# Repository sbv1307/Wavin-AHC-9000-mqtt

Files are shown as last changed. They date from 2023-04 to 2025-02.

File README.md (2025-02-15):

# **Wavin-AHC-9000-mqtt**

A Esp8266 mqtt interface for more Wavin AHC-9000 controllers connected together, configured and controlled by one Wavin display.

The goal is to be able to control the Wavin AHC 9000 heating controllers from [Home Assistant](https://www.home-assistant.io/) (HA), and still be able to use the Wavin display as well. However MODBUS specifications does not allow more than one master. The Wavin display will not be working together with the Esp8266 mqtt interface, at the same tine, in the current version. The current solution is to use a 4 poles toggle switch, to manually switch between the Esp8266 mqtt interface and the Wavin display.

The original goal of being able to control the Wavin AHC 9000 heating controllers from [OpenHAP](https://www.openhab.org/), has been abandoned because I gave up finding a discovery function for MQTT integrations, like the one in HA.

### **Operation**

The Esp8266 mqtt interface is generally operated from [HA](https://www.home-assistant.io/). When started, it will publish a configuration for each thermostat connected to a MQTT Broker, from where HA will pickup the configurations.

Besides controlling the single thermostat from HA, the Esp8266 mqtt interface provide a MQTT switch for HA named "Wavin interface operation mode", which provide an easy way to change the setpoints for all thermostats connected. Currently four operations modes are configured in the PrivateConfig.h file:
  
0. Normal operation
1. Holiday operation
2. Surplus heat operation
3. Maintenance operation**

These operations modes can also be selected by publishing a [JSON](https://en.wikipedia.org/wiki/JSON) to:
````bash
heat/floorE8DB84E05CC8/config

````
Publish the following JSON will set the operation mode to **Holiday operation**
````bash
{
  "opmode": "1"
}
````

**Maintenance operation:** This operation mode will set the setpoint temperature for all thermostats to maximum temperature (MAX_TEMP) and run in this mode for a period of time, and then return to previous operation mode. All parameters are defined in PrivateConfig.h

### **Current project status**

The Wavin AHC-9000 controllers are initial installed and configured using the Wavin display, which configures each controller's MOC-BUS device number.

Future solution might be to use a 2 Circuit IC Switch [CD4052B](https://www.ti.com/product/CD4052B-MIL#tech-docs), managed by the Esp8266 mqtt interface, to control which controller (Wavin display or Esp8266) will be in action.

### **History**

This project has started as a git clone of [dkjonas/Wavin-AHC-9000-mqtt](https://github.com/dkjonas/Wavin-AHC-9000-mqtt.git) but restructured for Firmware (FW), Software (SW) and Hardware (HW).

This project takes on the challenge mentioned in [Issue #3](https://github.com/dkjonas/Wavin-AHC-9000-mqtt/issues/3#issuecomment-435690672)

##### "connect two AHC's together and control them by one display. I think this is rather unusual setup, so my code doesn't handle this case; It can only control one AHC."

Another interesting project: [nic6911/Wavin-AHC-9000-mqtt](https://github.com/nic6911/Wavin-AHC-9000-mqtt)

## **Esp8266 mqtt interface**

See the cloned Firmware markdown [here](Firmware/README.md).

## **SOFTWARE**

### Configuration

src/PrivateConfig.h contains constants, that should be changed to fit your own setup.

#### Notes for some of the constants:
MODBUS_DEVICES[] 
>This array defines the Modbus device id, for the AHC9000 Control Units, connected.<br> 
When AHC9000 Control Units are connected together with the AHC9000 Touch Screen Display (Display), 
then Modbus ID's are configured by the Display.<br>
The ID's are in binary representation starting with 0x02<br>
Having two AHC9000 Control Units connected, the definition will be:
````bash
MODBUS_DEVICES[] = {0x02, 0x03};
````

NUMBER_OF_CHANNELS_MONITORED_PER_DEVICE[]
>This is an array, defines how many AHC9000 Thermostats are connected to / monitored by each AHC9000 Control Units.<br>
When 11 Thermostats are connected to AHC9000 Control Unit 0x02 and 4 Thermostats are connected to AHC9000 Control Unit 0x03, the definition vill be:
````bash
NUMBER_OF_CHANNELS_MONITORED_PER_DEVICE[] = {11, 4}
````

ELEMENT_OFFSET_ON_ROOMS_FOR_DEVICE[]
>This array is used to define number of elements in other arrays and to find specific element in in these other arrays.<br>
Elements in other arrays represents Thermostats connected.<br>
The first element in this array is always zero. <br>
The next element (the second element) is the number of Thermostats connected to the first AHC Controller. <br>
The third element is the number of Thermostats connected to the first AHC Controller plus the number of Thermostats connected to the second AHC Controller.
The foruth element is the number of Thermostats connected to the first AHC Controller plus the number of Thermostats connected to the second AHC Controller plus the number of Thermostats connected to the third AHC Controller.<br>
And so on...
The last element in this array will represent the total number of Thermostats conencted / monitored.<br>
This way number of elements in other arrays can be defined as:<br>
bool configurationPublished[PrivateConfig::ELEMENT_OFFSET_ON_ROOMS_FOR_DEVICE[PrivateConfig::NUMBER_OF_DEVICES]];
Elements in an array can be found by:<br>
configurationPublished[ (PrivateConfig::ELEMENT_OFFSET_ON_ROOMS_FOR_DEVICE[device]) + channel]<br>
Where "channel" represent the Thermostat for the "device" in question.
When 11 Thermostats are connected to AHC9000 Control Unit 0x02 and 4 Thermostats are connected to AHC9000 Control Unit 0x03, the definition vill be:
````bash
ELEMENT_OFFSET_ON_ROOMS_FOR_DEVICE[] = {0,11,15}
````

### Compiling

The sketch use [PubSubClient](https://docs.arduino.cc/libraries/pubsubclient/)2.6 and [ArduinoJson](https://github.com/bblanchon/ArduinoJson/releases)7.0.1. Add the following to the plarform.ini file.
````bash
lib_deps =
  PubSubClient@2.6
  bblanchon/ArduinoJson@7.0.1
````

Larger buffer is needed for HomeAssistant discovery messages, which are quite large.

Add the following to the plarform.ini file.
````bash
build_flags = -D MQTT_MAX_PACKET_SIZE=1024
````
Over The Air update (OTA) is implemented in main.cpp. 

Compiled with [PlatformIO](https://platformio.org/) installed in VS Code and adding the follow to platformio.ini the code will provide the possability of setting PlatformIO Project Environment to   `env:nodemcu_ota` and upload will happen OTA.

````bash
[env:nodemcu_ota]
extends = env:nodemcu
upload_protocol = espota
upload_port = <IP Address of NodeMCU>
````

## **Mosquitto broker**

### **Requirements**

- Raspberry Pi model B v1.2. Installed with Raspberry Pi OS Lite (32-bit) <span id="a1">[[1]](#f1)</span>.
- Internet access.
- Docker Engin and Docker Compose installed <span id="a2">[[2]](#f2)</span>.

### **Create docker-compose file**

In folder `Wavin-AHC-9000-mqtt` create file `docker-compose.yaml`

```bash
vi docker-compose.yaml
```

Add the following contend:

```bash
# Docker-compose file for building Wavin-AHC-9000-mqtt program stack.

# Generel note about environment settings - see README.md file about .env file

version: '3.8'

services:
  mosquitto-mqtt:
  container_name: mosquitto-mqtt
  image: eclipse-mosquitto:2
  restart: always
  command: mosquitto -c /mosquitto-no-auth.conf
  ports:
    - 1883:1883
  volumes:
    - mosquitto-conf:/mosquitto/config
    - mosquitto-data:/mosquitto/data
    - mosquitto-log:/mosquitto/log

volumes:
  mosquitto-conf:
    name: mosquitto-conf
  mosquitto-data:
    name: mosquitto-data
  mosquitto-log:
    name: mosquitto-log

````

 Start the docker container with `docker-compose up -d`.

```bash
docker-compose up -d
```

## Change LOG

| | Module | Version | Change
|--- |--- | ---- |----
| | | 0.0.1 | Initial commit. On-board LED at PIN 16 added to indicate active boot up. It turns off at successful connect to Wireless Lan. 
| FW | WavinController.h | 0.0.2 | MODBUS_DEVICE changed from = 0x01 to 0x02
| FW | WavinController.h | 0.0.3 | MODBUS_DEVICE changed from = 0x02 to 0x03
| FW | WavinController.h | 0.0.4 | Added MODBUS_DEVICES and NUMBER_OF_DEVIDES
| FW | WavinController.cpp | 0.0.4 | Objects modified to handle MODBUS_DEVICE as an argument instad of fixed value.
| FW | All modules | 0.0.4 | Calls to objects, which has changed because of the objects being modified for handle MODBUS_DEVICE as an argument. MQTT Publish functions has been added Modbus Device.
| FW | main.cpp | 0.0.5 | publishConfiguration() changed to comply with homeassistant topic.
| FW | main.cpp | 0.0.6 | Implementing OTA update.
| FW | main.cpp | 0.0.7 | OTA and temerature setting issues.
| FW | main.cpp & PrivateConfig.h | 0.0.8 | Configurable names for chanels added to PrivateConfig.h and implemented in mail.cpp
| FW | main.cpp | 0.0.9 | Re-arrange code structure. Insert function definitions, startup() and loot() in beginning.
| FW | main.cpp | 0.0.10 | #4: Insert WiFi reconnect postpone time <br>#5: call WiFi.disconnect() before "reconnect" (WiFi.mode(WIFI_STA) og WiFi.begin() <br>#2: Publish device info to MQTT broker
| FW | main.cpp | 0.0.11 | #3: implement Arduino JSON
| FW | main.cpp | 0.1.0  | #11: millis() overrun: Implementing sec() and change code from using milli seconds, to use secunds for timestamps
| FW | main.cpp | 0.1.1  | #10: Scan only installed sensors<br>PrivateConfig.h streamlined with WavinController.h. Global constants moved into class PrivateConfig as static ...
| FW | main.cpp | 0.1.2  | Tracking wavinController.readRegisters. This version publishes failed calls to readRegisters in order og verify how long it stakes before alle Thermostats are read.
| FW | main.cpp | 0.1.3  | #8: Implement reading of floor temperature
| FW | main.cpp | 0.1.4  | Track unsuccessful for calls to wavinController.readRegisters
| FW | main.cpp | 1.0.0  | #6: Preset functionality (Holiday function, Removal of surplus heat)
| FW | main.cpp | 1.1.0  | #9 Implement Maintenance fuktionality 
| FW | main.cpp | 1.2.0  | Setpoints 
| FW | main.cpp | 1.2.1  | Setpoints bugfixes.
| FW | main.cpp | 1.2.3  | #12 Set temperature not change, when changing operation mode 

###### "#n" Refers to github issue number

## Credits
- dkjonas/Wavin-AHC-9000-mqtt

#### **Footnotes**
=======
###### 1. <span id="f1"></span> See document: [Setting up and configure Raspberry Pi 3 MODEL B+ for the Docker Traefik router project](./docs/SettingUpRaspberryPi.md). [$\hookleftarrow$](#a1)

###### 2. <span id="f2"></span> See document [Install Docker Engin and Docker Compose](./docs/InstallDockerEnginAndCompose.md)[$\hookleftarrow$](#a3)

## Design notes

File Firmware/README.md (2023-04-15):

# Wavin-AHC-9000-mqtt
This is a simple Esp8266 mqtt interface for Wavin AHC-9000/Jablotron AC-116, with the goal of being able to control this heating controller from a home automation system.

## Hardware
The AHC-9000 uses modbus to communicate over a half duplex RS422 connection. It has two RJ45 connectors for this purpose, which can both be used. 
The following schematic shows how to connect an Esp8266 to the AHC-9000:
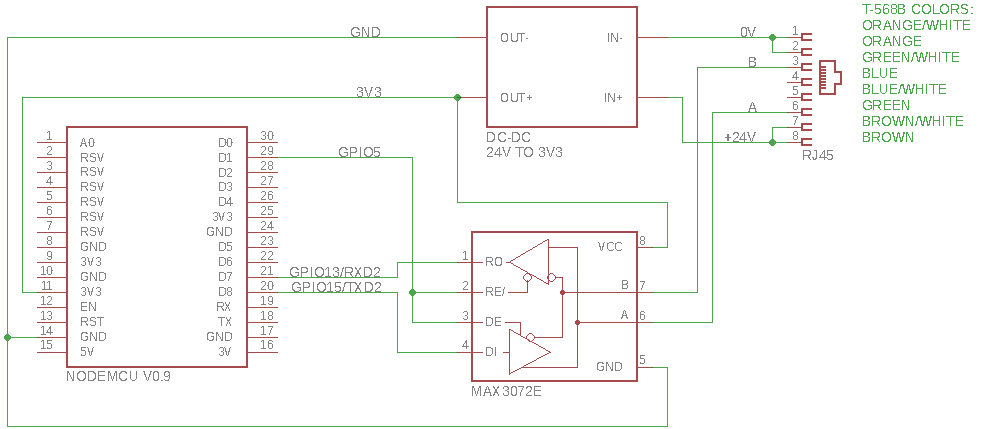
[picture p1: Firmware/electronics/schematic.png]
Schematic


Components with links to devices on eBay
* Esp8266. I use a [NodeMcu 0.9](https://www.ebay.com/itm/NEW-Version-NodeMcu-Lua-ESP8266-CH340-WIFI-Internet-Development-Board-Module/311413475392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), mostly because it is very convenient to have the onboard USB interface for programming. Almost anything with an Esp8266 on it will work.
* [24V to 3v3 switchmode converter](https://www.ebay.com/itm/DC-Buck-24V-12V-9V-to-3-3V-3A-Step-Down-Converter-Voltage-Regulator-Power-Module/173494900654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). This is only needed if you want to power the Esp8266 from the AHC-9000. A 24V to 5V converter can also be used, if it is connected to the +5V input of the NodeMcu. Please note that not all 3V3 step down converters on eBay supports 24V input
* [MAX3072E](https://www.maximintegrated.com/en/products/interface/transceivers/MAX3072E.html) for converting the 3V3 serial output from the Esp8266 to RS422. There are many similar IC's from other suppliers, which can also be used. Speed is limited, and cables can be kept short, so this is rather uncritical. Note though, that it should be a 3V3 version. [MAX3485](https://www.ebay.com/itm/5pcs-MAX3485CPA-DIP-DIP-8-MAX3485-3-3V-Powered-Transceiver-new/400985402735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) should be compatible, and can be found on eBay.
* RJ45 connector. This can be omitted by soldering a patch cable directly to the circuit.

Depending on the used Esp8266 board and/or the switchmode converter used, it may be benificial to add a larger capacitor in the range of 100uF between 3V3 and gnd.  This will most likely help if you experience WiFi connection/stability issues.

## Software

### Configuration
src/PrivateConfig.h contains 5 constants, that should be changed to fit your own setup.

`WIFI_SSID`, `WIFI_PASS`, `MQTT_SERVER`, `MQTT_USER`, and `MQTT_PASS`.

### Compiling
I use [PlatformIO](https://platformio.org/) for compiling, uploading, and and maintaining dependencies for my code. If you install PlatformIO in a supported editor, building this project is quite simple. Just open the directory containing `platformio.ini` from this project, and click build/upload. If you use a different board than nodemcu, remember to change the `board` variable in `platformio.ini`.
You may be able to use the Arduino tools with the esp8266 additions for compiling, but a few changes may be needed, including downloading dependencies manually.

### Testing
Assuming you have a working mqtt server setup, you should now be able to control your AHC-9000 using mqtt. If you have the [Mosquitto](https://mosquitto.org/) mqtt tools installed on your mqtt server, you can execude:
```
mosquitto_sub -u username -P password -t heat/# -v
```
to see all live updated parameters from the controller.

To change the target temperature for a output, use:
```
mosquitto_pub -u username -P password -t heat/floorXXXXXXXXXXXX/1/target_set -m 20.5
```
where the number 1 in the above command is the output you want to control and 20.5 is the target temperature in degree celcius. XXXXXXXXXXXX is the MAC address of the Esp8266, so it will be unique for your setup.

### Integration with HomeAssistant
If you have a working mqtt setup in [HomeAssistant](https://home-assistant.io/), all you need to do in order to control your heating from HomeAssistant is to enable auto discovery for mqtt in your `configuration.yaml`.
```
mqtt:
  discovery: true
  discovery_prefix: homeassistant
```
You will then get a climate and a battery sensor device for each configured output on the controller.

If you don't like auto discovery, you can add the entries manually. Create an entry for each output you want to control. Replace the number 0 in the topics with the id of the output and XXXXXXXXXXXX with the MAC of the Esp8266 (can be determined with the mosquitto_sub command shown above)
```
climate wavinAhc9000:
  - platform: mqtt
    name: floor_kitchen
    current_temperature_topic: "heat/floorXXXXXXXXXXXX/0/current"
    temperature_command_topic: "heat/floorXXXXXXXXXXXX/0/target_set"
    temperature_state_topic: "heat/floorXXXXXXXXXXXX/0/target"
    mode_command_topic: "heat/floorXXXXXXXXXXXX/0/mode_set"
    mode_state_topic: "heat/floorXXXXXXXXXXXX/0/mode"
    modes:
      - "heat"
      - "off"
    availability_topic: "heat/floorXXXXXXXXXXXX/online"
    payload_available: "True"
    payload_not_available: "False"
    qos: 0

sensor wavinBattery:
  - platform: mqtt
    state_topic: "heat/floorXXXXXXXXXXXX/0/battery"
    availability_topic: "heat/floorXXXXXXXXXXXX/online"
    payload_available: "True"
    payload_not_available: "False"
    name: floor_kitchen_battery
    unit_of_measurement: "%"
    device_class: battery
    qos: 0
```

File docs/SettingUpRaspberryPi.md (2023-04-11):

# Setting up and configure Raspberry Pi 3 MODEL B+ for the Docker projects

## Pre-requisuits:
    • USB Keyboard
    • Terminal kabel (HDMI → VGA)
    • LAN kabel (Internet access)
    • Raspberry Pi
    • FAST SC kort

## Setting up SD card:
Using Raspberry Pi Imanager to create SD Card installed with Raspberry Pi OS Lite (32-bit).

See: [Setting up your Raspberry Pi](https://projects.raspberrypi.org/en/projects/raspberry-pi-setting-up/2) for detailed instructions.

## Configure Raspberry Pi 3 MODEL B+ for the Docker projects

    • Connet: 
      - LAN kabel (Internet access), 
      - local keyboard and
      - terminal.
    • Take a note about LAN address at boot up.
    • Boot up and log in as:
      - User: pi
      - Passwd: raspberry

## Run Raspberry Pi configuration by executing

````bash
sudo raspi-config
````

### Update this tool to lates version - Main menu item 8

    • Select item: 8 Update this tool to latest version.

### System options - Main menu item 1:

##### As the pi will be running in a demilitarized zone, wireless network will not be configured.

    • Submenu S4 Hostname = pi-mqtt
    • Submenu S6 Network at Boot = Yes

### Interface Options - Main menu item 3:
    • Submenu P2 SSH = remote command line access using SSH = Enable.

### Perfoamance Options - Main menu item 4:
    • P4 Fan: GPIO 18 → Temp: 80.

### Localisation Options - Main menu item 5:
    • L1 Locale →  add:  da_DK-UTF-8 UTF-8
    • L2 TimeZone → Europe → Copenhagen.
    • L3 Keyboard → Generid 105-key PC (intl) → Danish (With Win keys) → default → No comppose key.

### Advanced Options - Main menu item 6:
    • A1 Expand Filesystem.

## **Exit raspi-config and reboot** -> Login and verify IP addresses

<br>

# From here on - Connect via SSH with PUTTY
## Update OS: 
```bash
 sudo apt-get update
 sudo apt-get -y upgrade –fix-missing
 sudo reboot now

```

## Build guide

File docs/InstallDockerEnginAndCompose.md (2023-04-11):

# Install Docker Engin and Docker Compose

## **Log in as mqttmgr and run the commands below:**

## remove any previously docker installation.
```bash
sudo apt-get remove docker docker-engine docker.io containerd runc
````

Expected output:

````bash
Reading package lists... Done
Building dependency tree... Done
Reading state information... Done
E: Unable to locate package docker-engine
````

## Get docker engine and run install schript
```bash
curl -sSL https://get.docker.com | sh
```

## Enable user ”mqttmgr” to run docker withour using sudo
```bash
sudo usermod -aG docker mqttmgr
```

## **Log out and log in again to run docker commands withour sudo**
```bash
exit
```

## Test docker installation
```bash
docker run hello-world
```
If the installation of docker is successful, then message **Hello from Docker!** will show up.

## Clean up docker to verify docker-compose
```bash
docker rm -f  $(docker ps -aq)
```
```bash
docker rmi $(docker images -aq)
```

## Install dependincies for installing docker compose
```bash
sudo apt-get install -y libffi-dev libssl-dev
```
```bash
sudo apt-get install -y python3 python3-pip
```
```bash
sudo apt-get remove python-configparser

```

## Install docker compose
```bash
sudo pip3 -v install docker-compose
```

## Test docker-compose:
On Linux host create file **docker-compose.yml** and adde the following lines:
```bash
version: '3.4'
services:
  hello-world:
    image: hello-world
```
PS: If using **vi**, the folowing commands are usefull:
```bash
vi docker-compose.yml   # Will open the vi editor
a                       # for "add" will place the editor in insermode and add characters into the editor window
[ESC]                   # Exit wil exit insertmode mode. 
:[Ctrl-V][Ctrl-Q]       # Will: enter command line (:), Write to file [Ctrl-V] and exit vi [Ctrl-V][Ctrl-Q].
```

## Next: run the docker-compose command to verify the installation
```bash
docker-compose up
```

   If the installation of docker is successful, then message **Hello from Docker!** will show up.

## Clean up docker environment.
```bash
docker rm -f  $(docker ps -aq)
```
```bash
docker rmi $(docker images -aq)
```
```bash
docker system prune -f –volumes
```
```bash
rm docker-compose.yml
```

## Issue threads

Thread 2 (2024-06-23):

Publish device info to MQTT broker

sbv1307, 2024-06-23:
At startup Sketch version, SSID and IP address as retained payload to MQTT broker.
It just makes it easier to locate the device for OTA update.

Closed 2024-06-25.

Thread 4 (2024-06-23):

Insert WiFi reconnect postpone time

sbv1307, 2024-06-23:
In csse of WiFi connect issues, the sketch keeps retryíng without a break (pause).
To prevnet an overload, implement a WiFiConnectPostpone.

Closed 2024-06-25.

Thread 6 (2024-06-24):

Preset functionality (Holiday function, Removal of surplus heat)

sbv1307, 2024-06-24:
Add functionality which by one command, can set an individual  presat low temperatur i every room

sbv1307, 2024-06-27:
Merged #7 into this issue, because the solution will be the same.
Solution:
- Define a structure, which will hold the setpoint temperature for each thermostat. The structure shall handle setpoints for "Normal operationmode", "Holyday operationmode" and "Surplus heat operationmode".
- An element in the structure for the given operation, will be updated, when ever the setpoint is read from the thermostat, and has a new value.
- When an operationmode changes, setpoints the current operationmode will be saved to memory, and the setpoints for new operationmode will be read from memory and the thermostats will be updated.

Closed 2025-01-22.

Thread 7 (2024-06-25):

Removal of surplus heat

sbv1307, 2024-06-25:
A functionality, which by one command can increase the temperature in more rooms.

sbv1307, 2024-06-27:
Merged into #6

Closed 2024-06-27.

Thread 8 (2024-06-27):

Implement reading of floor temperature

sbv1307, 2024-06-27:
For rooms controlled by a room thermostat with IR temperatur sensor, floor temperature can be read at address 0x05 in the elements register.
In WavinControoler.h ADD:
- static const uint8_t ELEMENTS_FLOOR_TEMPERATURE = 0x05;

In Main.cpp, the section where CATEGORY_ELEMENTS are read:
Add logic to extract the floor temperature, for those thermostats which has an IR sensor.

sbv1307, 2024-11-26:
Issue: Setting temperature for Thermostatus with IR. Currently is seems as if they are to be set differently, as the temperature fore these Thermostats show a high temlerature...

sbv1307, 2024-12-09:
V0.1.3 implements reading and showing floor temperature.
It's based on information, that the register for floor temperature is zero (0), if the Thermostat does not have an IR sensor installed.

Solution awaits test

Closed 2025-01-22.

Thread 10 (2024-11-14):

Scan only installed sensors

sbv1307, 2024-11-14:
Current all 16 channels are scanned. This needs to be reduced to the actual number of sensors installed.

Currently not a big issue, but when trying to implement preset function for hollyday and normal operation, it seems to become an issue.

sbv1307, 2024-12-09:
implemented in version 0.1.1

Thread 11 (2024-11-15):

millis() overrun

sbv1307, 2024-11-15:
Polling all channels og all devices is supposed to be done for every POLL_TIME_MS ( Currently 5000 ) milliseconds.
Polling is when:
lastUpdateTime + POLL_TIME_MS < millis()
And
lastUpdateTime = millis()
Is set when polling is done.
This leaves the issue if if millis( overruns while lastUpdateTime + POLL_TIME_MS si set to a value close to 2^32,

Solution:
/*
 * ###################################################################################################
 *              S E C   -   S Y S T E M T I M E    I N   S E C U N D S
 * ###################################################################################################
 *
 * sec()
 *
 * [Time]
 *
 * Description
 *
 * Returns the number of secunds passed since the board began running the current program.
 * This number will overflow (go back to zero), after approximately 136 years.
 *
 * Syntax
 *
 * time = millis()
 *
 * Parameters
 *
 * None
 *
 * Returns
 *
 * Number of seconds passed since the program started. Data type: unsigned long.
 *
 * NOTE: The function is based on the ESP Timer (High Resolution Timer), the function esp_timer_get_time() returns a 64 bit value in microseconds.
 *
 *
 * Example Code
 * This example code prints on the serial port the number of seconds passed since the board started running the code itself.
 unsigned long myTime;

void setup() {
  Serial.begin(9600);
}
void loop() {
  Serial.print("Time: ");
  myTime = sec();

  Serial.println(myTime); // prints time since program started
  delay(1000);          // wait a second so as not to send massive amounts of data
}
 *
 */

unsigned long sec()
{
  int64_t m = esp_timer_get_time();
  unsigned long s = m / 1000000;
  return s;
}

sbv1307, 2024-11-21:
As the exp8266 framework does not support esp_timer_get_time(). The solution has been to find a workaround.
The solution has been to modify the sec() as followes:
/*
 * ###################################################################################################
 *              S E C   -   S Y S T E M T I M E    I N   S E C U N D S
 * ###################################################################################################
 *
 * sec()
 *
 * [Time]
 *
 * Description
 *
 * Returns the number of secunds passed since the board began running the current program.
 * This number will overflow (go back to zero), after approximately 136 years.
 *
 * This version is based on millis(), which overflows (go back to zero), after approximately 50 days.
 * It requires a two global variables:
 * - uint16_t millisOverruns: To keeb track on, how many overruns has occoured.
 * - unsigned long secLastCalledAt: To keep track on, when an overrun has occoured.
 *
 * Limitations
 *
 * The function has to be called at least a couple of times, within approximately 50 days to keep track
 * of overruns.
 *
 * Syntax
 *
 * time = sec()
 *
 * Parameters
 *
 * None
 *
 * Returns
 *
 * Number of seconds passed since the program started. Data type: unsigned long.
 *
 * Example Code
 * This example code prints on the serial port the number of seconds passed since the board started running the code itself.

unsigned long myTime;

// Variables used by SEC() to keep track on millis() overruns
uint16_t millisOverruns;
unsigned long secLastCalledAt;
// Fundcion definition.
unsigned long sec();

void setup() {
  Serial.begin(9600);
}

void loop() {
  Serial.print("Time: ");
  unsigned long myTime = sec();

  Serial.println(myTime); // prints time since program started
  delay(1000);          // wait a second so as not to send massive amounts of data
}
 *
 */

unsigned long sec()
{
  unsigned long m = millis();

  if ( m < secLastCalledAt)
    millisOverruns++;

  secLastCalledAt = m;

  return (millisOverruns * (pow(2, 32) / 1000)) + ( m / 1000);
}

sbv1307, 2024-11-21:
Implemented in ver. 0.1.1

Closed 2024-11-21.

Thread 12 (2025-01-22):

Set temperature not change, when changing operation mode

sbv1307, 2025-01-22:
Setpoint version 1.2.0 has implemented issues: #6, #8, #9 and #10.

However temperature is not set when changing Operation mode, eventhoguit worked in test setup.

sbv1307, 2025-02-15:
Implemented in version V1.2.3

Closed 2025-02-15.

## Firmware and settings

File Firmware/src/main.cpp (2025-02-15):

#include <ArduinoJson.h>
#include <ArduinoOTA.h>
#include <ESP8266WiFi.h>
#include <PubSubClient.h>
#include <EEPROM.h>
#include "WavinController.h"
#include "PrivateConfig.h"

#define SKETCH_VERSION "Esp8266 MQTT Wavin AHC 9000 interface - V1.2.3"

#define ALT_LED_BUILTIN 16


/*
 * This version change registration of setpoints read.
 * In previous versions, all setpoints had to be read successfully in the same poll cycle before the setpoints were updated.
 * In his version, setpoints are registerted un til all setpoints have been read successfully. Then the setpoints are updated.
 * 
 * V1.2.3-1 - Clean code for spelling and grammar.
 * V1.2.3-2 - Clean code for debugging and remove debug messages.
 * Issues now documented on github
 * Version history documented in README.md
 */

/*
 * ######################################################################################################################################
 * ######################################################################################################################################
 *                       V  A  R  I  A  B  L  E      D  E  F  I  N  A  I  T  O  N  S
 * ######################################################################################################################################
 * ######################################################################################################################################
 */

#define WIFI_CONNECT_POSTPONE 30        // Number of Seconds between WiFi connect attempts, when WiFi.begin fails to connect.
#define MQTT_CONNECT_POSTPONE 30        // Number of Seconds between MQTT connect dattempts, when MQTT connect fails to connect.

#define RETAINED true                   // Used in MQTT publications. Can be changed during development and bugfixing.

#define CONFIGURATION_VERSION 1

// MQTT definitions
// Esp8266 MAC will be added to the device name, to ensure unique topics
// Default is topics like 'heat/floorXXXXXXXXXXXX/1/3/target', where 1 is the Modbus Device number and 3 is the output id and XXXXXXXXXXXX is the mac

const String   MQTT_PREFIX              = "heat/";       // include tailing '/' in prefix
const String   MQTT_PREFIX_DEVICE       = "wavin";
const String   MQTT_PREFIX_STATUS       = "wavin";
const String   MQTT_DEVICE_NAME         = "floor";       // only alfanumeric and no '/'
const String   MQTT_ONLINE              = "/online";      
const String   MQTT_DISCOVERY_PREFIX    = "homeassistant/";       // include tailing '/' in discovery prefix!
const String   MQTT_COMPONENT_SELECT    = "select/";
const String   MQTT_SKETCH_VERSION      = "/sketch_version";
const String   MQTT_SUFFIX_CURRENT      = "/current";    // include heading '/' in all suffixes
const String   MQTT_SUFFIX_SETPOINT_GET = "/target";
const String   MQTT_SUFFIX_SETPOINT_SET = "/target_set";
const String   MQTT_SUFFIX_MODE_GET     = "/mode";
const String   MQTT_SUFFIX_MODE_SET     = "/mode_set";
const String   MQTT_SUFFIX_BATTERY      = "/battery";
const String   MQTT_SUFFIX_OUTPUT       = "/output";
const String   MQTT_SUFFIX_CONFIG        = "/config";
const String   MQTT_SUFFIX_STATUS       = "/status";


const String   MQTT_VALUE_MODE_STANDBY  = "off";
const String   MQTT_VALUE_MODE_MANUAL   = "heat";

const String   MQTT_CLIENT = "Wavin-AHC-9000-mqtt";       // mqtt client_id prefix. Will be suffixed with Esp8266 mac to make it unique
const String   MQTT_OPERATION_MODE = "opmode";

String mqttDeviceNameWithMac;
String mqttClientWithMac;

static const  uint8_t NUMBER_OF_DEVICES = sizeof(PrivateConfig::NUMBER_OF_CHANNELS_MONITORED_PER_DEVICE) / sizeof(uint8_t); // Do NOT Change !!!

// Operating mode is controlled by the MQTT_SUFFIX_MODE_ topic.
// When mode is set to MQTT_VALUE_MODE_MANUAL, temperature is set to the value of MQTT_SUFFIX_SETPOINT_
// When mode is set to MQTT_VALUE_MODE_STANDBY, the following temperature will be used
const float STANDBY_TEMPERATURE_DEG = 5.0;

const uint8_t TX_ENABLE_PIN = 5;
const bool SWAP_SERIAL_PINS = true;
const uint16_t RECEIVE_TIMEOUT_MS = 1000;
WavinController wavinController(TX_ENABLE_PIN, SWAP_SERIAL_PINS, RECEIVE_TIMEOUT_MS);

WiFiClient wifiClient;
PubSubClient mqttClient(wifiClient);

unsigned long lastUpdateTime = 0;       // Timestamp in Seconds when channels were read and HA updated.
unsigned long maintenanceModeSetAt = 0; // Timestamp in Seconds when maintenance mode were set.
unsigned long setpointChangedAt = 0;

/* Variables to handle connect postpone */
unsigned long WiFiConnectAttempt = 0;   // Timestamp in Seconds when an attempt to connect to WiFi were done
unsigned long MQTTConnectAttempt = 0;   // Timestamp in Seconds when an attempt to connect to MQtT were done

unsigned long WiFiConnectPostpone = 0;  // Seconds between each attempt to connect to WiFi.
unsigned long MQTTConnectPostpone = 0;  // Seconds between each attempt to connect to MQTT.

// ToBeRemoved >>>>>>>>>>>     T E S T: Set OLL_TIME_SEC = 5 after test has finished
const uint16_t POLL_TIME_SEC = 30;        // Seconds between each poll of channels

// Create a structure for each channel on all heat controllers controlled by this project.
struct lastKnownValue_t {
  uint16_t temperature;
  uint16_t setpoint;
  uint16_t battery;
  uint16_t status;
  uint16_t mode;
} lastSentValues[ PrivateConfig::ELEMENT_OFFSET_ON_ROOMS_FOR_DEVICE[NUMBER_OF_DEVICES]];


struct operationMode_t {
  uint8_t structureVersion;
  uint16_t setpoint[ PrivateConfig::ELEMENT_OFFSET_ON_ROOMS_FOR_DEVICE[NUMBER_OF_DEVICES]];
} operationModes[  PrivateConfig::NUMBER_OF_OPERATION_MODES];

bool setpointChanged = false;
uint8_t currentOperationmode = 0;       // 0 = Normal, 1 = Holiday, 2 = Surplus heat, 3 = Maintenance
uint8_t previousOperationmode = 0;      // Stores the previous operation mode while running in maintenance mode.
u_int8_t numberOfThermostatsRead = 0;

const uint16_t LAST_VALUE_UNKNOWN = 0xFFFF;

const uint16_t EEPROM_START_ADDRESS = 0; //EEPROM address to start reading from

int setpointMask[NUMBER_OF_DEVICES];

bool changeOperationMode = false;
bool operationModeUnavailable = true;
bool configurationPublished[ PrivateConfig::ELEMENT_OFFSET_ON_ROOMS_FOR_DEVICE[NUMBER_OF_DEVICES]];
bool updateEEPROM = false;

/* ########################################################################################################
 * ########################################################################################################
 * ########################################################################################################
 * ########################################################################################################
 * ##########################    F U N C T I O N    D E C L A R A T I O N S    ##############################
 * ########################################################################################################
 * ########################################################################################################
 * ########################################################################################################
 * ########################################################################################################
*/
String temperatureAsFloatString(uint16_t);
uint8_t getIdFromTopic(char*);
uint8_t getModbusDeviceFromTopic(char*);
uint16_t temperatureFromString(String);
int readSetpoint( uint8_t, uint8_t, uint16_t registers[11]);
void delayForOAT(uint16_t);
void publishIfNewValue(String, String, uint16_t, uint16_t*);
void mqttCallback(char*, byte*, unsigned int);
void resetLastSentValues();
void presetBitmask();
void publishConfiguration(uint8_t device, uint8_t channel);
void publishOperationModeConfiguration();
void publish_sketch_version();
void setNewOperationMode( uint8_t );

/* Variables only used by SEC() to keep track on millis() overruns*/
uint16_t millisOverruns = 0;
unsigned long secLastCalledAt = 0;
unsigned long sec();
void publishStatus( String );

/* ########################################################################################################
 * ########################################################################################################
 * ########################################################################################################
 * ################################   S E T U P     B E G I N   ###########################################
 * ########################################################################################################
 * ########################################################################################################
 * ########################################################################################################
 */
void setup()
{
  pinMode(ALT_LED_BUILTIN, OUTPUT);   // Initialize the LED pin as an output
  digitalWrite(ALT_LED_BUILTIN, LOW); // Turn the LED on to indicate initialization and not connected for WiFi 
                                      //(Note that LOW is the voltage level

  // Get last operation mode and the setpoints for normal operation mode. 
  int eeAddress = EEPROM_START_ADDRESS;
  EEPROM.begin(512);
  EEPROM.get( eeAddress, currentOperationmode );
  EEPROM.get( eeAddress + sizeof(currentOperationmode) + 
              (currentOperationmode * sizeof(operationModes[currentOperationmode])), 
              operationModes[currentOperationmode]
            );
  EEPROM.end();

  // Verify if operation modes have been used at all by verifying if structure version for normal operation mode
  // equals current CONFIGURATION_VERSION
  if ( operationModes[currentOperationmode].structureVersion != CONFIGURATION_VERSION)
  {
    // Normal operation mod have not beed set. Fill structure with known values.
    currentOperationmode = 0;
    operationModes[currentOperationmode].structureVersion = CONFIGURATION_VERSION;
    for(int8_t i = 0; i < ( PrivateConfig::ELEMENT_OFFSET_ON_ROOMS_FOR_DEVICE[NUMBER_OF_DEVICES]); i++)
    {
      operationModes[currentOperationmode].setpoint[ i] = 0;
    }
  } else
    changeOperationMode = true;

  // Get mac address and create strings for MQTT topics
  uint8_t mac[6];
  WiFi.macAddress(mac);

  char macStr[13] = {0};
  sprintf(macStr, "%02X%02X%02X%02X%02X%02X", mac[0], mac[1], mac[2], mac[3], mac[4], mac[5]);

  mqttDeviceNameWithMac = String(MQTT_DEVICE_NAME + macStr);
  mqttClientWithMac = String(MQTT_CLIENT + macStr);

  // Set MQTT 
  mqttClient.setServer(PrivateConfig::MQTT_SERVER.c_str(), PrivateConfig::MQTT_PORT);
  mqttClient.setCallback(mqttCallback);

  /*
   * Enable OTA update
   */
  ArduinoOTA.begin();
}
/* ########################################################################################################
 * ########################################################################################################
 * ########################################################################################################
 * ################################     L O O P    B E G I N    ###########################################
 * ########################################################################################################
 * ########################################################################################################
 * ########################################################################################################
 */
void loop()
{
  /* If not connected to WiFi, connect to WiFi*/
  if (WiFi.status() != WL_CONNECTED and sec() > WiFiConnectAttempt + WiFiConnectPostpone)
  {
    digitalWrite(ALT_LED_BUILTIN, LOW);  // Turn ON the LED to indicate WL connections is lost.
    
    WiFi.disconnect();
    WiFi.mode(WIFI_STA);
    WiFi.begin(PrivateConfig::WIFI_SSID.c_str(), PrivateConfig::WIFI_PASS.c_str());

    if (WiFi.waitForConnectResult() != WL_CONNECTED)
    {
      WiFiConnectAttempt = sec();
      WiFiConnectPostpone = WIFI_CONNECT_POSTPONE;
      return;
    } 
    else
    {
      WiFiConnectAttempt = 0;   // In case WiFi is lost, attempt to reconnect immediately. 
      WiFiConnectPostpone = 0;
    }
  }

  if (WiFi.status() == WL_CONNECTED)
  {
    // Check for over the air update request and (if present) flash it
    ArduinoOTA.handle();
  
    digitalWrite(ALT_LED_BUILTIN, HIGH);  // Turn the LED off to indicate WL is connected
    /* If not connected to MQTT broker, connect to MQTT broker*/
    if (!mqttClient.connected() and sec() > MQTTConnectAttempt + MQTTConnectPostpone )
    {
      String will = String(MQTT_PREFIX + mqttDeviceNameWithMac + MQTT_ONLINE);
      if ( mqttClient.connect(mqttClientWithMac.c_str(), 
                              PrivateConfig::MQTT_USER.c_str(), 
                              PrivateConfig::MQTT_PASS.c_str(), 
                              will.c_str(), 1, true, "False") 
          )
      {
        MQTTConnectAttempt = 0;
        MQTTConnectPostpone = 0;

        // When connected to MQTT broker, publish: Sketch version, SSID connected, IP address and current operation mode.
        publish_sketch_version();

        /* Subscribe to: Setpoint set, Mode set and configuration. */
        String setpointSetTopic = String(MQTT_PREFIX + mqttDeviceNameWithMac + "/+/+" + MQTT_SUFFIX_SETPOINT_SET);
        mqttClient.subscribe(setpointSetTopic.c_str(), 1);
        
        String modeSetTopic = String(MQTT_PREFIX + mqttDeviceNameWithMac + "/+/+" + MQTT_SUFFIX_MODE_SET);
        mqttClient.subscribe(modeSetTopic.c_str(), 1);
        
        String configSetTopic   = String(MQTT_PREFIX + mqttDeviceNameWithMac + MQTT_SUFFIX_CONFIG);
        mqttClient.subscribe(configSetTopic.c_str(), 1);

       /* Publish: will, operation configuration, current operation ode and make selection of operation modes unavailable */
        mqttClient.publish(will.c_str(), (const uint8_t *)"True", 4, RETAINED);

        publishOperationModeConfiguration();

        /* Publish current operation mode */
        String Topic = String(MQTT_DISCOVERY_PREFIX + MQTT_COMPONENT_SELECT + MQTT_PREFIX_DEVICE + "/state");
        String payload = String(currentOperationmode);
        mqttClient.publish( Topic.c_str(), payload.c_str(), RETAINED);

        /* Make switch operation mode unavailable */
        String switchTopic = String(MQTT_PREFIX + mqttDeviceNameWithMac + MQTT_SUFFIX_CONFIG + MQTT_ONLINE);
        mqttClient.publish(switchTopic.c_str(), (const uint8_t *)"False", 5, RETAINED);
        operationModeUnavailable = true;

        /* Forces resending of all parameters to server */
        resetLastSentValues();
        
        /* clear bitmask for which setpoints have been updated. */
        presetBitmask();

      }
      else
      {
        MQTTConnectAttempt = sec();
        MQTTConnectPostpone = MQTT_CONNECT_POSTPONE;
        return;
      }
    }
  
    /* Process incoming messages and maintain connection to the server */
    if(!mqttClient.loop())
    {
        return;     // Exit loop to attempt reconnection, if connections has gone lost
    }
    
    /* Walk through the Registers to poll data from each thermostat. */
    if (lastUpdateTime + POLL_TIME_SEC < sec() || changeOperationMode || setpointChanged)
    {
      bool allSetpointsRead = true;

      uint16_t registers[11];
      for(uint8_t device = 0; device < NUMBER_OF_DEVICES; device++)
      {
        for(uint8_t channel = 0; channel < PrivateConfig::NUMBER_OF_CHANNELS_MONITORED_PER_DEVICE[device]; channel++)
        {
          if ( ((changeOperationMode || setpointChanged) && bitRead(setpointMask[device], channel) == 0) ||
                !(changeOperationMode || setpointChanged)
             )
          {
            if ( wavinController.readRegisters( PrivateConfig::MODBUS_DEVICES[device], 
                                                WavinController::CATEGORY_CHANNELS,
                                                channel,
                                                WavinController::CHANNELS_PRIMARY_ELEMENT, 
                                                1, 
                                                registers
                                              )
                )
            {
              uint16_t primaryElement = registers[0] & WavinController::CHANNELS_PRIMARY_ELEMENT_ELEMENT_MASK;
              bool allThermostatsLost = registers[0] & WavinController::CHANNELS_PRIMARY_ELEMENT_ALL_TP_LOST_MASK;

              if(primaryElement == 0)
              {
                  // Channel not used
                  continue;
              }

              /* Publish configuration if not polished. */
              if(!configurationPublished[  PrivateConfig::ELEMENT_OFFSET_ON_ROOMS_FOR_DEVICE[device] + channel])
              {
                uint16_t standbyTemperature = STANDBY_TEMPERATURE_DEG * 10;
                wavinController.writeRegister( PrivateConfig::MODBUS_DEVICES[device], 
                                              WavinController::CATEGORY_PACKED_DATA, 
                                              channel, 
                                              WavinController::PACKED_DATA_STANDBY_TEMPERATURE, 
                                              standbyTemperature
                                            );
                publishConfiguration(device, channel);
              }

              delayForOAT(125);
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
void loop() {
  Serial.print("Time: ");
  unsigned long myTime = sec();

  Serial.println(myTime); // prints time since program started
  delay(1000);          // wait a second so as not to send massive amounts of data
}
 *
 */

unsigned long sec()
{
  unsigned long m = millis();

  if ( m < secLastCalledAt)
    millisOverruns++;

  secLastCalledAt = m;

  return (millisOverruns * (pow(2, 32) / 1000)) + ( m / 1000);
}

/* ###################################################################################################
 *                P U B L I S H   O P E R A T I O N M O D E    c o n f i g u r a t i o n
 * ###################################################################################################
 * publishOperationModeConfiguration()
 * Description:   Publish operation mode MQTT switch to HA
 * Syntax: publishOperationModeConfiguration( )
 * Parameters:
 *  -  none
 * Returns: nothing
 */
/*
topic: homeassistant/select/wavin/config
payload: 
 -------------------------------------
{
"name":"Wavin interface operation mode",
"unique_id":"floor_XXXXXXXXXXXX",
"command_topic":"homeassistant/select/wavin/select",
"command_template" : "opmode:{{ this.attributes.options.index(value) }}",
"options":["Normal operation", "Holiday operation", "Surplus heat operation", "Maintenance operation"],
"state_topic":"homeassistant/select/wavin/state",
"value_template":"{{ this.attributes.options[(value | int)] }}"
}

topic: homeassistant/select/wavin/state
payload: 0, 1, 2 or 3  (0 = Normal, 1 = Holiday, 2 = Surplus heat, 3 = Maintenance)
*/
void publishOperationModeConfiguration()
{
  uint8_t payload[1024];
  JsonDocument Doc;

  Doc["name"] = String("Wavin interface operation mode");
  Doc["unique_id"] = String(mqttDeviceNameWithMac + "_" + MQTT_PREFIX_DEVICE);
  Doc["command_topic"] = String(MQTT_PREFIX + mqttDeviceNameWithMac + MQTT_SUFFIX_CONFIG);
  
  Doc["command_template"] = String( "{\"" + MQTT_OPERATION_MODE + "\": \"" +\
                            String("{{ this.attributes.options.index(value) }}") +  "\" }");
  
  for (uint8_t ii = 0; ii <  PrivateConfig::NUMBER_OF_OPERATION_MODES; ii++)
  {
    Doc["options"][ii] = String(  PrivateConfig::NAME_OF_OPERATION_MODES[ii]);
  }
  
  Doc["state_topic"] = String(MQTT_DISCOVERY_PREFIX + MQTT_COMPONENT_SELECT + MQTT_PREFIX_DEVICE + "/state");
  Doc["value_template"] = String("{{ this.attributes.options[(value | int)] }}");
  
  Doc["availability_topic"] = String(MQTT_PREFIX + mqttDeviceNameWithMac + MQTT_SUFFIX_CONFIG + MQTT_ONLINE);
  Doc["payload_available"] = "True";
  Doc["payload_not_available"] = "False";

  size_t length = serializeJson(Doc, payload);
  String Topic = String(MQTT_DISCOVERY_PREFIX + MQTT_COMPONENT_SELECT + MQTT_PREFIX_DEVICE + MQTT_SUFFIX_CONFIG);
  
  mqttClient.publish(Topic.c_str(), payload, length, RETAINED);
}

/*
 * ###################################################################################################
 *              P U B L I S H   S T A T U S
 * ###################################################################################################
 * Subscribe to: heat/+/status
 */
void publishStatus( String statusMessage)
{
  String topic = String(MQTT_PREFIX + mqttDeviceNameWithMac + MQTT_SUFFIX_STATUS);
  mqttClient.publish( topic.c_str(), statusMessage.c_str(), false);
}

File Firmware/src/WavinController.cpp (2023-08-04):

#include <ESP8266WiFi.h>
#include "WavinController.h"


WavinController::WavinController(uint8_t pin, bool swapSerialPins, uint16_t timeout_ms)
{
  txEnablePin = pin;
  digitalWrite(pin, LOW);
  pinMode(pin, OUTPUT);

  recieveTimeout_ms = timeout_ms;

  Serial.begin(38400);

  if(swapSerialPins)
  {
    Serial.swap();
  }
}


unsigned int WavinController::calculateCRC(uint8_t *frame, uint8_t bufferSize)
{
  uint16_t temp = 0xFFFF;
  bool flag;

  for (uint8_t i = 0; i < bufferSize; i++)
  {
    temp = temp ^ frame[i];
    for (uint8_t j = 1; j <= 8; j++)
    {
      flag = temp & 0x0001;
      temp >>= 1;
      if (flag)
      {
        temp ^= 0xA001;
      }
    }
  }

  return temp;
}


bool WavinController::recieve(uint16_t *reply, uint8_t modbusDevice, uint8_t cmdtype)
{
  uint8_t buffer[RECIEVE_BUFFER_SIZE];
  uint8_t n = 0;
  unsigned long start_time = millis();

  while (millis() - start_time < recieveTimeout_ms)
  {
    while (Serial.available() && n<RECIEVE_BUFFER_SIZE)
    {
      buffer[n] = Serial.read();
      n++;

      if (n > 5 &&
        buffer[0] == modbusDevice &&
        buffer[1] == cmdtype &&
        buffer[2] + 5 == n)
      {
        // Complete package
        uint16_t crc = calculateCRC(buffer, n);
        if (crc != 0) return false;

        // CRC ok, copy to reply buffer
        for (int j = 0; j < buffer[2] / 2; j++)
        {
          reply[j] = (buffer[3 + j * 2] << 8) + buffer[4 + j * 2];
        }
        return true;
      }
    }
  }
  return false;
}


void WavinController::transmit(uint8_t *data, uint8_t lenght)
{
  // Empty recieve buffer before sending
  while (Serial.read() != -1);

  digitalWrite(txEnablePin, HIGH);

  Serial.write(data, lenght);

  Serial.flush(); // Wait for data to be sent
  delayMicroseconds(250); // Wait for last char to be transmitted

  digitalWrite(txEnablePin, LOW);
}


bool WavinController::readRegisters(uint8_t modbusDevice, uint8_t category, uint8_t page, uint8_t index, uint8_t count, uint16_t *reply)
{
  uint8_t message[8];

  message[0] = modbusDevice;
  message[1] = MODBUS_READ_REGISTER;
  message[2] = category;
  message[3] = index;
  message[4] = page;
  message[5] = count;

  uint16_t crc = calculateCRC(message, 6);

  message[6] = crc & 0xFF;
  message[7] = crc >> 8;

  transmit(message, 8);

  return recieve(reply, modbusDevice, MODBUS_READ_REGISTER);
}


bool WavinController::writeRegister(uint8_t modbusDevice, uint8_t category, uint8_t page, uint8_t index, uint16_t value)
{
  uint8_t message[10];

  message[0] = modbusDevice;
  message[1] = MODBUS_WRITE_REGISTER;
  message[2] = category;
  message[3] = index;
  message[4] = page;
  message[5] = 1;
  message[6] = value >> 8;
  message[7] = value & 0xFF;

  uint16_t crc = calculateCRC(message, 8);

  message[8] = crc & 0xFF;
  message[9] = crc >> 8;

  transmit(message, 10);

  uint16_t reply[1];
  return recieve(reply, modbusDevice, MODBUS_WRITE_REGISTER); // Recieve reply but ignore it. Asume it's ok
}

bool WavinController::writeMaskedRegister(uint8_t modbusDevice, uint8_t category, uint8_t page, uint8_t index, uint16_t value, uint16_t mask)
{
  uint8_t message[12];

  message[0] = modbusDevice;
  message[1] = MODBUS_WRITE_MASKED_REGISTER;
  message[2] = category;
  message[3] = index;
  message[4] = page;
  message[5] = 1;
  message[6] = value >> 8;
  message[7] = value & 0xFF;
  message[8] = mask >> 8;
  message[9] = mask & 0xFF;

  uint16_t crc = calculateCRC(message, 10);

  message[10] = crc & 0xFF;
  message[11] = crc >> 8;

  transmit(message, 12);

  uint16_t reply[1];
  return recieve(reply, modbusDevice, MODBUS_WRITE_MASKED_REGISTER); // Recieve reply but ignore it. Asume it's ok
}

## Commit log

2023-04-15 FW: Buildin LED at PIN 16 added to indicate connected to WiFI. DOC: documents moved and README modified
2023-08-03 FRMW: Added delays in the shape of calls to ArduinoOTA.handle
2023-08-05 DOC: README.md updated to reflect current statu of the project
2024-06-18 DOC: Issues added to main
    [main.cpp]
2024-06-25 DOC: Issues moved out of sketch and into githup
    [main.cpp]
2024-06-25 FRM: Issues #2, #4 & #5 implemented
    [main.cpp]
2024-11-21 FRM: sec() implemented to handle millis() overrun, Calls to millis() changed to calls to sec()
2024-11-26 FRM: Tracking calls to wavinController.readRegisters by publishing status to MQTT broker
    [main.cpp]
2024-11-29 FRM: #8: Implement reading of floor temperature and publishMessage now requires MQTT sufix
2024-12-09 FRM: Track Failed calls to Track Failed calls to wavinController.readRegisters
    [main.cpp]
2025-02-14 Bugfixes for change operationmode
    [main.cpp]
2025-12-07 PCB added to projekt
    [Wavin-AHC-9000-mqtt-B_Cu.gbr, Wavin-AHC-9000-mqtt-B_Mask.gbr, Wavin-AHC-9000-mqtt-B_Paste.gbr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]
